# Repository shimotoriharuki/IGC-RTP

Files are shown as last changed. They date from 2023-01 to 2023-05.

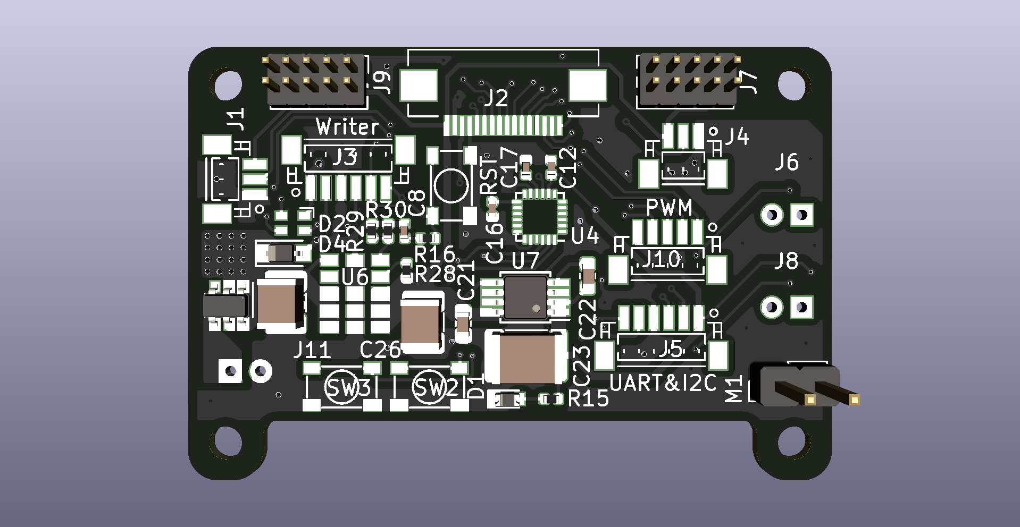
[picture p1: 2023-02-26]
Circuit/main_circuit/robotraceV5-F.png

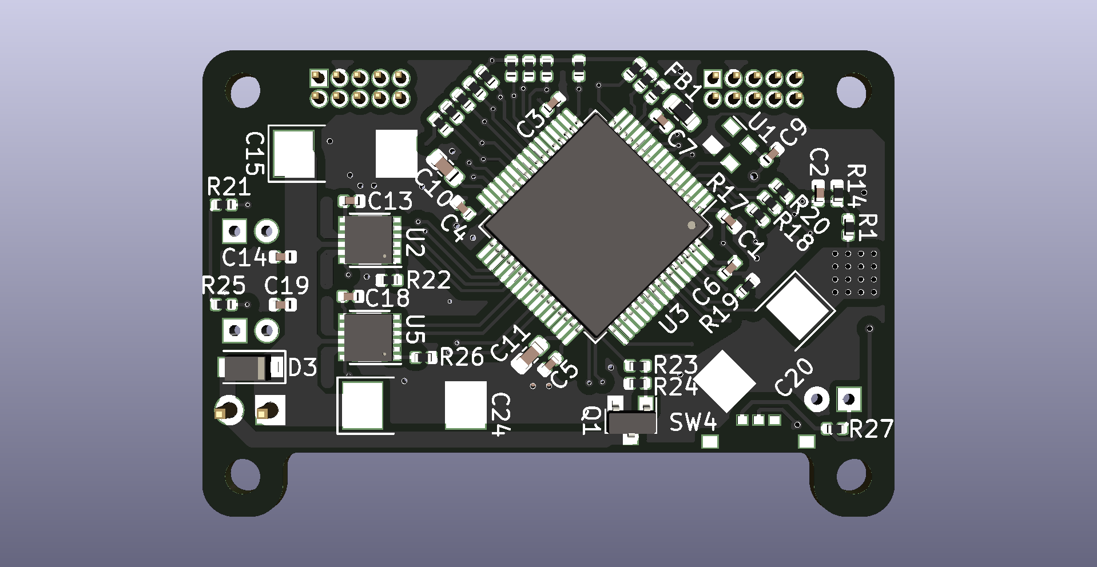
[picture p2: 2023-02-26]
Circuit/main_circuit/robotraceV5-B.png

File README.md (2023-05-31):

# IGC-RTP

IGC-RTPのソフトウェアが含まれるリポジトリです．

# 環境

- CubeIDE 1.5.1
- KiCad 6.0

# 導入方法（たぶん）
1. このリポジトリをフォーク 
2. フォークしたリポジトリをCubeIDEのワークスペースにクローン

（ワークスペースの場所は，Windowsのデフォルトだと `C:\Users\<ユーザー名>\STM32CubeIDE\workspace_<バージョン>`

```
cd <ワークスペースのパス>
git clone https://github.com/shimotoriharuki/IGC-RTP
```

3. CubeIDEを開いて「C/C++ Project」ウィンドウで右クリック
4. 「Import」をクリック
5. 「General」の中にある「Existing Projects int Workspace」をクリック
6. 「Browse」ボタンをクリックしてクローンしてきたディレクトリを選択
# 運用方法
* 基本的にフォークしたリポジトリで開発してください
* コミットは頻繁にして，コミットメッセージは意味のあるものにしてください
* なにか機能を追加したらGitHubからプルリクを送ってください
* `UserSelection.h`で自分の名前のマクロを有効にしてゲインなどのパラメータを切り替えてください．自分の名前以外のマクロはコメントアウトしてください
# 変更の確認手順

```shell
git fetch origin <テストしたいブランチ名>
```

## before

```shell
git remote add upstream <フォーク元のURL> # フォーク元のURLをupstreamという名前で登録 一度やればOK
git fetch upstream # upstreamの変更をローカルに持ってくる
git merge upstream/<ブランチ名> # マスターに変更を持ってくる
```

* https://leico.github.io/TechnicalNote/Git/pull-fork-origin

# Circuitについて

Circuitディレクトリにある制作物は
[IGC8810](https://github.com/IGC8810)の著作物です。許可を得てこのリポジトリで公開しています。

# LICENSE

このソフトウェアパッケージは[3条項BSDのライセンス](https://github.com/shimotoriharuki/IGC-RTP/blob/master/LICENSE)の下、再頒布および使用が使用が許可されます．

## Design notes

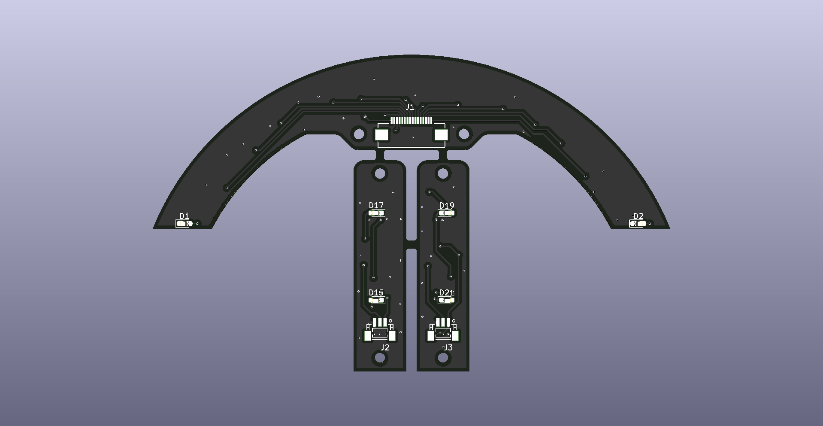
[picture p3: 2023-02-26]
Circuit/sensor_circuit/robotrace_sensorV4_F.png

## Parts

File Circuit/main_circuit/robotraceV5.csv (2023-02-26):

Reference | Quantity | Value | Footprint | Datasheet
C10 C11 | 2 | 2.2ƒÊ | Capacitor_SMD:C_0603_1608Metric | ~
C13 C18 | 2 | 1ƒÊ | Capacitor_SMD:C_0402_1005Metric | ~
C15 C20 | 2 | 68ƒÊ | mcr0:OScapacitor_ECAS | ~
C21 | 1 | 1ƒÊ | Capacitor_SMD:C_0603_1608Metric | ~
C22 | 1 | 0.01ƒÊ | Capacitor_SMD:C_0603_1608Metric | ~
C23 | 1 | 10ƒÊ | Capacitor_SMD:C_1812_4532Metric | ~
C24 | 1 | 100ƒÊ | mcr0:OScapacitor_ECAS | ~
C25 C26 | 2 | 22ƒÊ | Capacitor_SMD:C_1210_3225Metric | ~
C7 C9 C8 C14 C19 C3 C1 C6 C5 C4 C12 C16 C2 C17 | 14 | 0.1ƒÊ | Capacitor_SMD:C_0402_1005Metric | ~
D1 | 1 | green | Diodes_SMD:D_0603 | ~
D2 | 1 | OSTB0603C1C-A | mcr0:OSTB0603C1C-A
D3 | 1 | SS2040FL | Diodes_SMD:D_SOD-123F | ~
D4 | 1 | 14 | Diodes_SMD:D_SOD-323_HandSoldering | ~
FB1 | 1 | Ferrite | Resistor_SMD:R_0603_1608Metric | ~
J10 | 1 | PWM | Connectors_JST:JST_SH_BM05B-SRSS-TB_05x1.00mm_Straight | ~
J11 | 1 | Battery | mcr0:PAconn_01x02 | ~
J2 | 1 | LineADC_IN | mcr0:CN-FFC-SMT2(CN-FFC(0.5)16PD) | ~
J3 | 1 | Debugger | Connectors_JST:JST_SH_BM06B-SRSS-TB_06x1.00mm_Straight | ~
J4 J1 | 2 | maker_IN | Connectors_JST:JST_SH_BM03B-SRSS-TB_03x1.00mm_Straight | ~
J5 | 1 | I2C&UART | Connectors_JST:JST_SH_BM06B-SRSS-TB_06x1.00mm_Straight | ~
J6 J8 | 2 | Motor | mcr0:PAconn_01x02 | ~
J9 J7 | 2 | FTSH-105-01-F-D-K | Pin_Headers:Pin_Header_Straight_2x05_Pitch1.27mm | ~
M1 | 1 | Fan | Pin_Headers:Pin_Header_Straight_1x02_Pitch2.54mm | ~
Q1 | 1 | 2N7002K | Package_TO_SOT_SMD:SOT-23 | https://www.diodes.com/assets/Datasheets/ds30896.pdf
Q2 | 1 | SSM6J808R | mcr0:TSOP-6F_P0.95mm | http://akizukidenshi.com/catalog/g/gI-10454/
R1 | 1 | 2.4k | Resistor_SMD:R_0402_1005Metric | ~
R14 | 1 | 620 | Resistor_SMD:R_0402_1005Metric | ~
R16 | 1 | 100 | Resistor_SMD:R_0402_1005Metric | ~
R17 R29 | 2 | 1.2k | Resistor_SMD:R_0402_1005Metric | ~
R18 | 1 | 680 | Resistor_SMD:R_0402_1005Metric | ~
R19 R21 R25 R15 R28 | 5 | 10k | Resistor_SMD:R_0402_1005Metric | ~
R2 R3 R4 R5 R6 R7 R8 R9 R10 R11 R12 R13 | 12 | R | Resistor_SMD:R_0402_1005Metric | ~
R20 R23 | 2 | 470 | Resistor_SMD:R_0402_1005Metric | ~
R22 R26 | 2 | 14k | Resistor_SMD:R_0402_1005Metric | ~
R27 R24 | 2 | 47k | Resistor_SMD:R_0402_1005Metric | ~
R30 | 1 | 150 | Resistor_SMD:R_0402_1005Metric | ~
SW1 SW3 SW2 | 3 | SW_Push | mylib:SKRPACE010 | ~
SW4 | 1 | SSAJ120100 | mcr0:SSAJ120100 | ~
U1 | 1 | ASDMB-12MHz | Oscillator:Oscillator_SMD_Abracon_ASDMB-4Pin_2.5x2.0mm | https://abracon.com/Oscillators/ASDMB.pdf
U2 U5 | 2 | MAX22201ATC | Package_DFN_QFN:DFN-12-1EP_3x3mm_P0.5mm_EP2.05x2.86mm
U3 | 1 | STM32F405RGTx | Package_QFP:LQFP-64_10x10mm_P0.5mm | http://www.st.com/st-web-ui/static/active/en/resource/technical/document/datasheet/DM00037051.pdf
U4 | 1 | ICM-20648 or MPU-6500 | Sensor_Motion:InvenSense_QFN-24_3x3mm_P0.4mm | http://www.invensense.com/wp-content/uploads/2016/06/DS-000189-ICM-20948-v1.3.pdf
U6 | 1 | LXDC55F | mylib:LXDC55F
U7 | 1 | LT1763-3.3 | Package_SO:MSOP-8_3x3mm_P0.65mm | https://www.analog.com/media/en/technical-documentation/data-sheets/1962fb.pdf

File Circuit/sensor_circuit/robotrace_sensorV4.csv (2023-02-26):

Reference | Quantity | Value | Footprint | Datasheet
C1 C2 C3 C8 C7 C6 C5 C4 C10 C9 C11 C13 C12 C14 | 14 | 0.1ƒÊ | Capacitor_SMD:C_0603_1608Metric | ~
D1 D2 D15 D17 D21 D19 | 6 | LED | LED_SMD:LED_0603_1608Metric_Castellated | ~
D9 D3 D8 D14 D7 D13 D6 D12 D5 D11 D4 D10 D16 D18 D20 D22 | 16 | IRLED | LED_SMD:LED_0603_1608Metric_Castellated | ~
J1 | 1 | line_sens | mcr0:CN-FFC-SMT2(CN-FFC(0.5)16PD) | ~
J2 | 1 | maker_outL | Connectors_JST:JST_SH_BM03B-SRSS-TB_03x1.00mm_Straight | ~
J3 | 1 | maker_outR | Connectors_JST:JST_SH_BM03B-SRSS-TB_03x1.00mm_Straight | ~
Q1 Q2 Q3 Q4 Q5 Q6 Q7 Q8 Q9 Q10 Q11 Q12 | 12 | PT | LED_SMD:LED_0603_1608Metric_Castellated | ~
R1 R2 R15 R18 R24 R21 | 6 | 1k | Resistor_SMD:R_0603_1608Metric | ~
R16 R19 R22 R25 | 4 | 100 | Resistor_SMD:R_0603_1608Metric | ~
R3 R8 R7 R6 R5 R4 R17 R20 R23 R26 | 10 | 10k | Resistor_SMD:R_0603_1608Metric | ~
R9 R14 R13 R12 R11 R10 | 6 | 4 | Resistor_SMD:R_0603_1608Metric | ~
U1 U6 U5 U4 U3 U2 | 6 | NJU6080 | TO_SOT_Packages_SMD:SOT-23-6
U7 U9 U10 U12 | 4 | S7136 | mcr0:S7136 | https://akizukidenshi.com/catalog/g/gI-02425/
U8 U11 | 2 | TC7S32F | Package_SO:TSOP-5_1.65x3.05mm_P0.95mm | http://www.ti.com/lit/sg/scyt129e/scyt129e.pdf

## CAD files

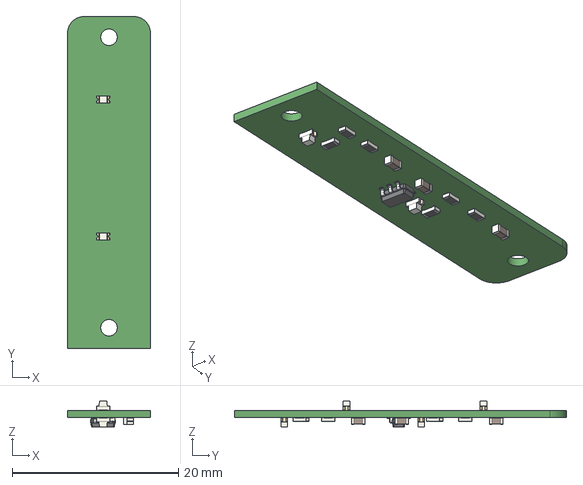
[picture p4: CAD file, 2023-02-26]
Circuit/sensor_circuit/robotrace_sensorV4_left_sens_only.step
10.0 x 40.0 x 3.10 mm

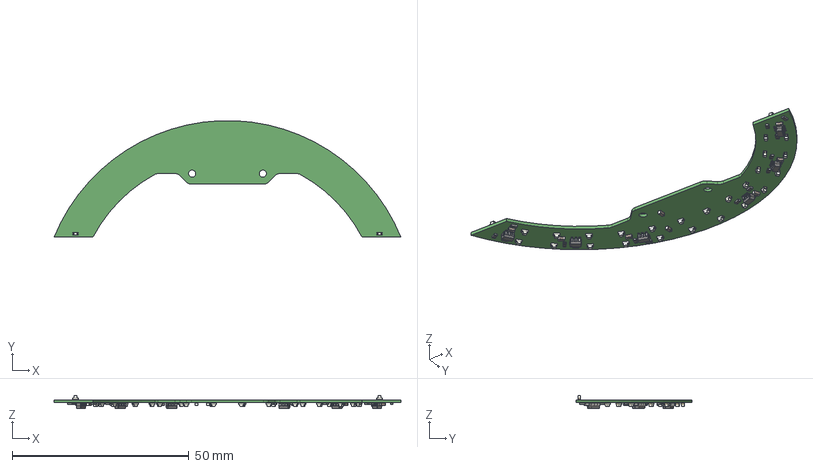
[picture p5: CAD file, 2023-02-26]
Circuit/sensor_circuit/robotrace_sensorV4_line_sens_only.step
98.2 x 32.9 x 3.55 mm

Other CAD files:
Circuit/sensor_circuit/robotrace_sensorV4_right_sens_only.step

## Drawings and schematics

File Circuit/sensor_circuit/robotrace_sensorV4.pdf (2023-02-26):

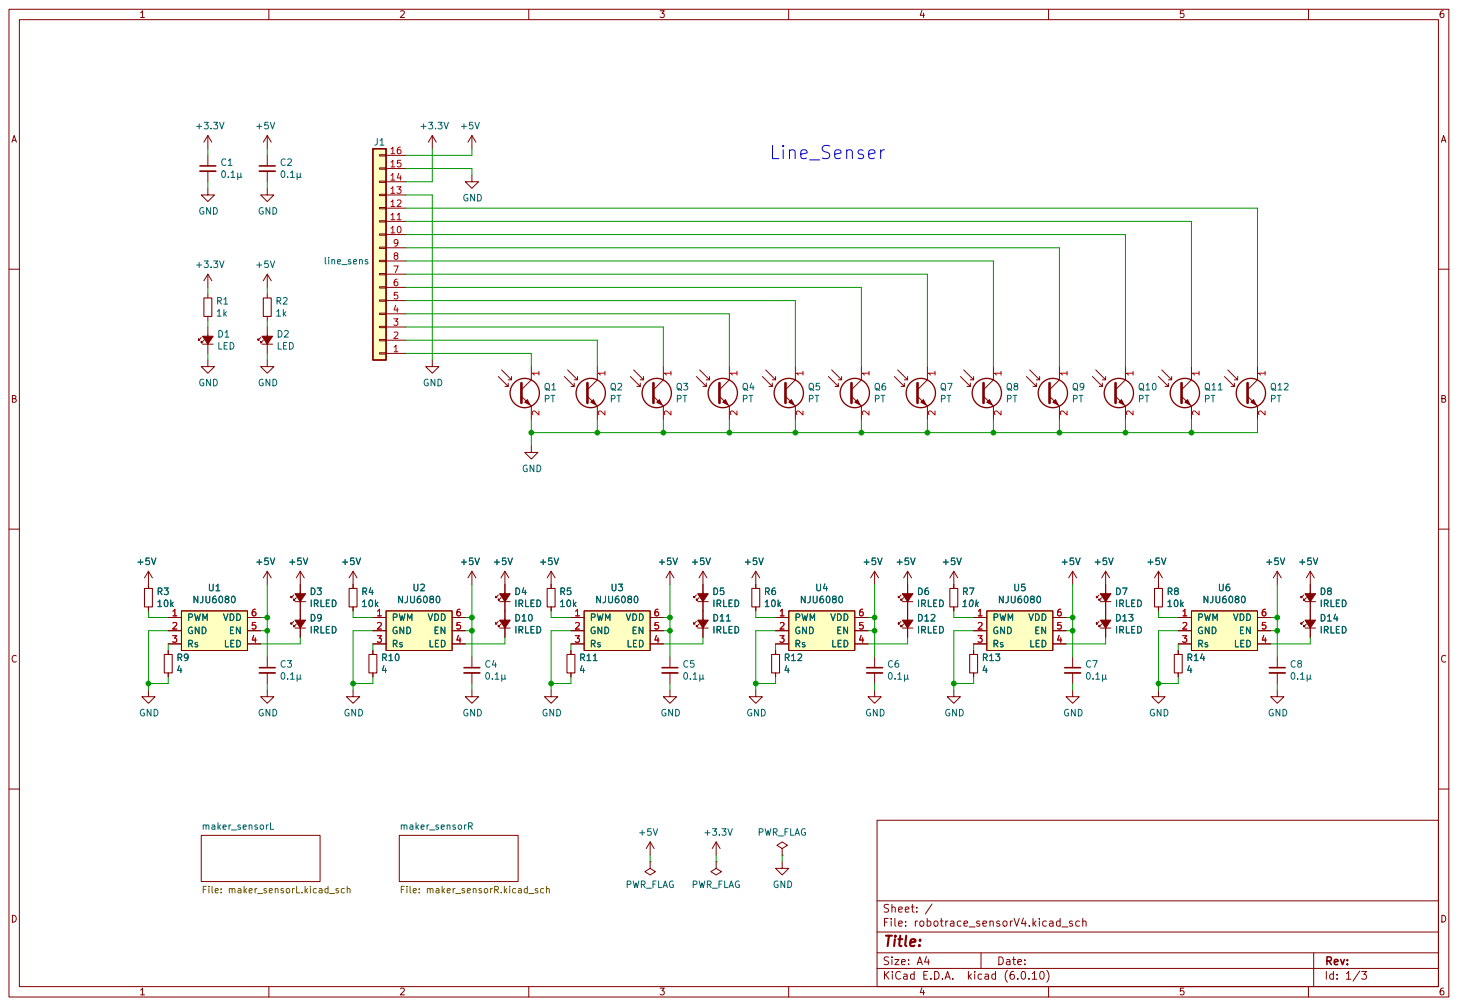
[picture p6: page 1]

11
10

1 2 Q5 PT PWM 1 GND 2 Rs 3

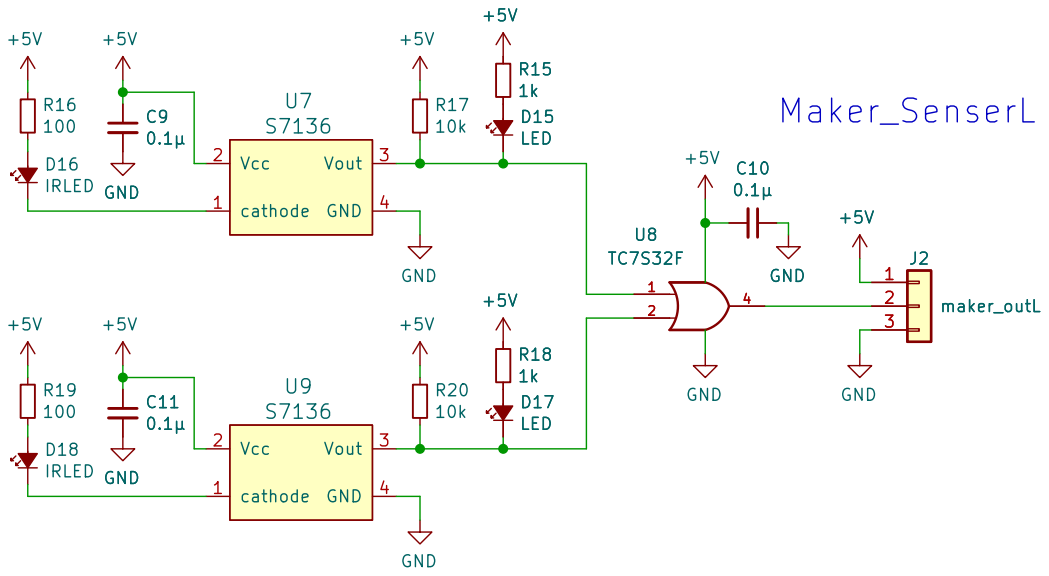
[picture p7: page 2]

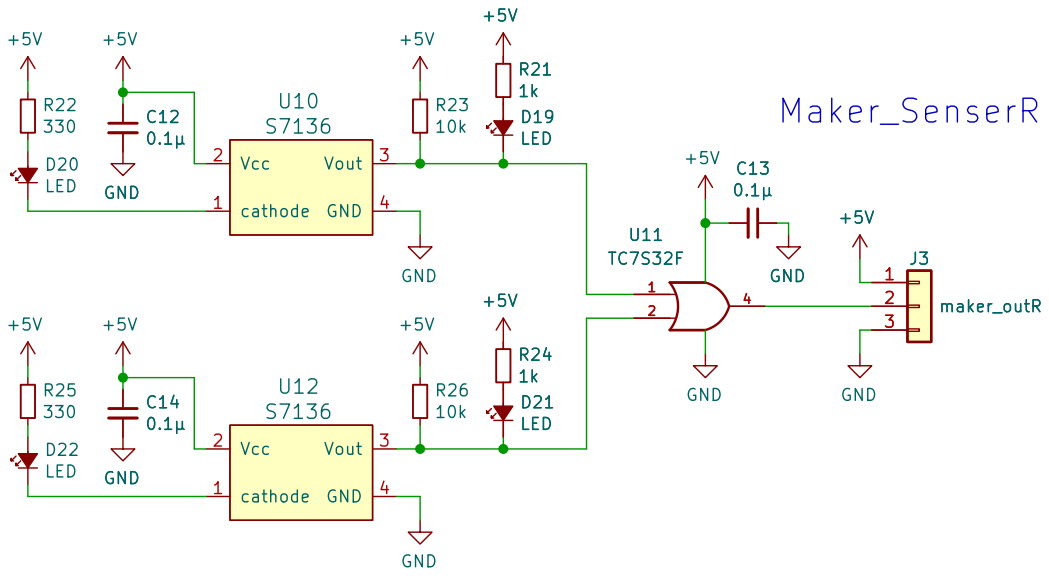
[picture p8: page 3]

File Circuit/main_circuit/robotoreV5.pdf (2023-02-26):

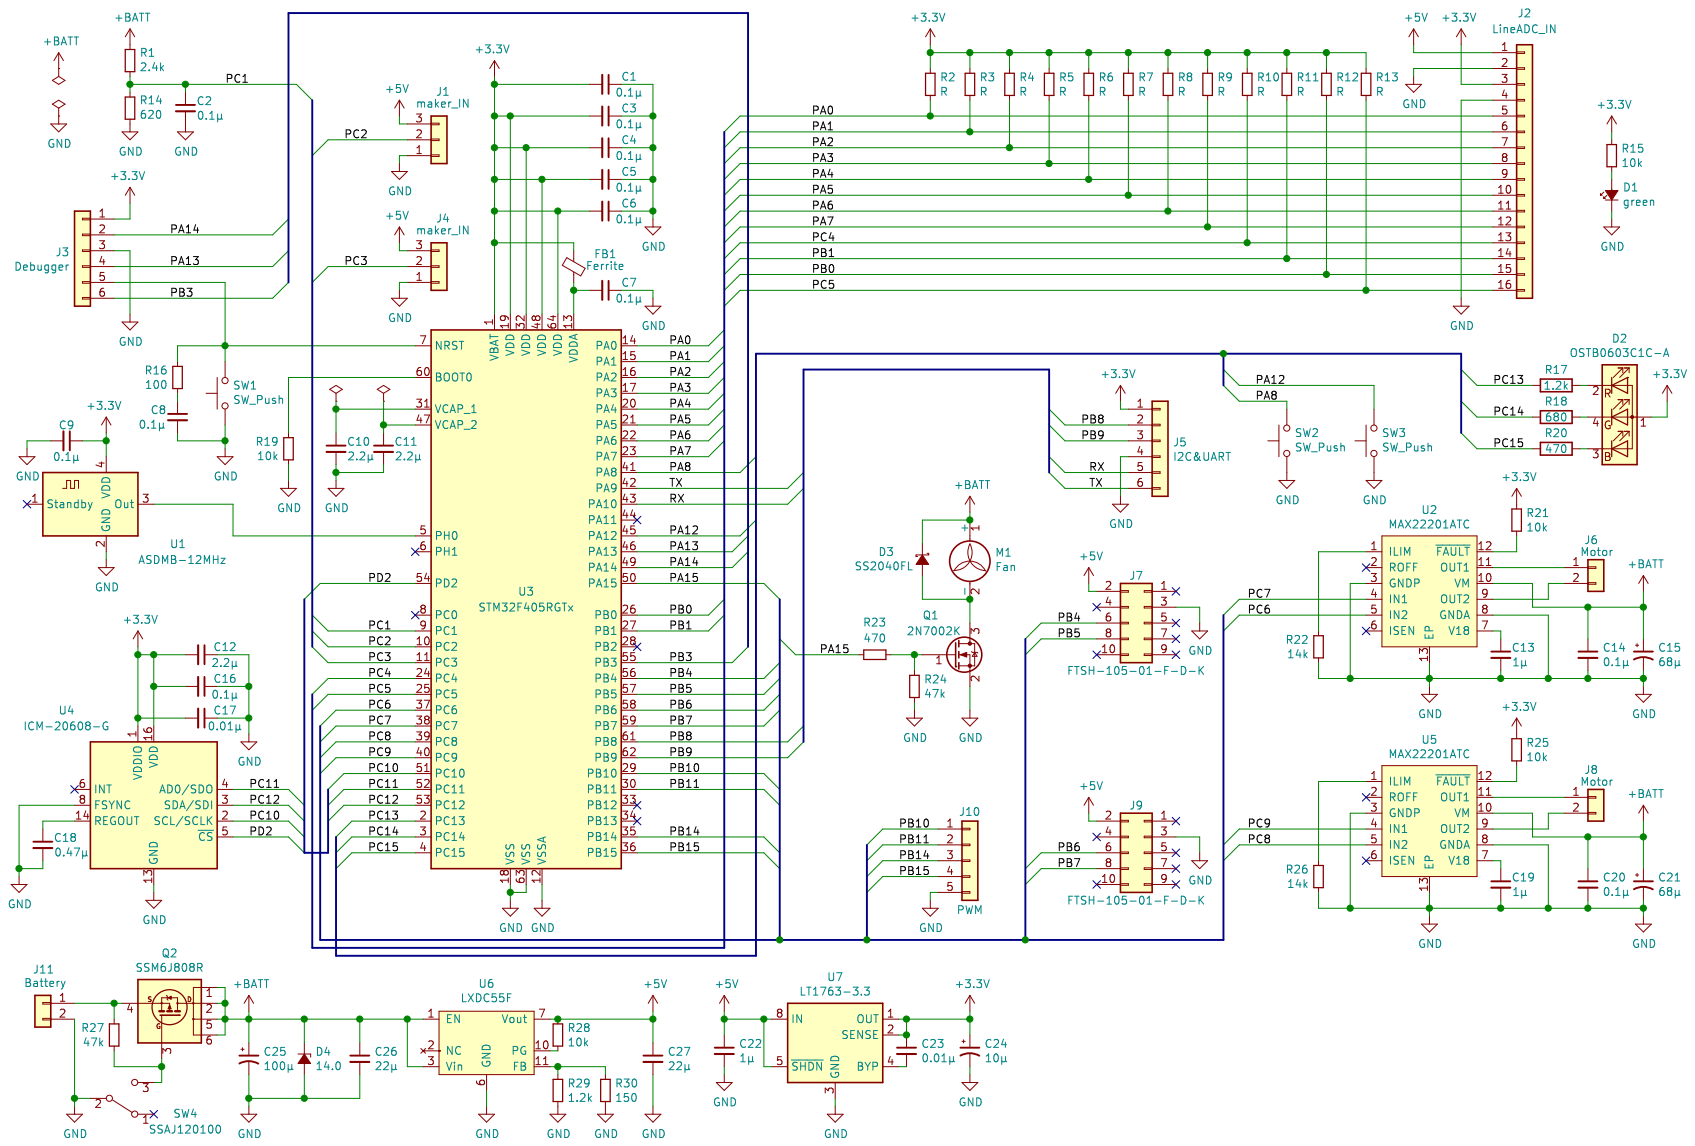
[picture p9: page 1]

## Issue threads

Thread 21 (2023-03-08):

マイコンがリセット状態だとファンが回る

shimotoriharuki, 2023-03-08:
書き込み中やリセットボタン押している間だとPA15がHIGHになるらしく，ファンがずっと回り続ける．
モータに1s以上の電圧をかけたくないのでソフトウェアでリミットをかけているが，リセット時に回られるとリミットが効かないのでなんとかしたい．

shimotoriharuki, 2023-03-08:
リセット時のマイコンのピンの状態を指定できるとよさげ．

shimotoriharuki, 2023-03-10:
マイコンリセット時にFETのゲート電圧がどうなっているか確認してけろ

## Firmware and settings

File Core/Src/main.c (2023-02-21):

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
/* Includes ------------------------------------------------------------------*/
#include "main.h"

/* USER CODE BEGIN Includes */
#include "Motor.h"
#include "LineSensor.h"
#include "SideSensor.h"
#include "LineChase.h"
#include "Running.h"
#include "MPU6500.h"
#include "IMU.h"
#include "LED.h"
#include "Switch.h"
#include "BatteryChecker.h"
#include "stdio.h"
#include "Logger.h"

/* USER CODE END Includes */

ADC_HandleTypeDef hadc1;
ADC_HandleTypeDef hadc2;
DMA_HandleTypeDef hdma_adc1;
DMA_HandleTypeDef hdma_adc2;

I2C_HandleTypeDef hi2c1;

SPI_HandleTypeDef hspi3;

TIM_HandleTypeDef htim2;
TIM_HandleTypeDef htim3;
TIM_HandleTypeDef htim4;
TIM_HandleTypeDef htim6;
TIM_HandleTypeDef htim7;
TIM_HandleTypeDef htim8;
TIM_HandleTypeDef htim12;

UART_HandleTypeDef huart1;

/* USER CODE BEGIN PV */

uint32_t timer, timer1;
uint16_t second_run_flag;

uint16_t mode_selector = 0;



/* USER CODE END PV */

void SystemClock_Config(void);
static void MX_GPIO_Init(void);
static void MX_DMA_Init(void);
static void MX_ADC1_Init(void);
static void MX_I2C1_Init(void);
static void MX_TIM2_Init(void);
static void MX_TIM3_Init(void);
static void MX_TIM4_Init(void);
static void MX_TIM8_Init(void);
static void MX_SPI3_Init(void);
static void MX_TIM12_Init(void);
static void MX_USART1_UART_Init(void);
static void MX_TIM6_Init(void);
static void MX_TIM7_Init(void);
static void MX_ADC2_Init(void);
/* USER CODE BEGIN 0 */
#ifdef __GNUC__
	#define PUTCHAR_PROTOTYPE int __io_putchar(int ch)
#else
	#define PUTCHAR_PROTOTYPE int fputc(int ch, FILE *f)
#endif /*__GNUC__*/

PUTCHAR_PROTOTYPE{
	HAL_UART_Transmit(&huart1, (uint8_t*)&ch, 1, 0xFFFF);
	return ch;
}

void HAL_TIM_PeriodElapsedCallback(TIM_HandleTypeDef *htim)
{
   if(htim->Instance == TIM6){ //1ms
		timer++;
		updateEncoderCnt(); //Do not move from HERE!!

		batteryCheckFlip();
		updateIMUValue();
		updateAnalogSensor();
		updateSideSensorStatus();

		calculateVelocityControlFlip();
		calculateLineFollowingTermFlip();
		lineTraceFlip();
		checkCourseOut();

		runningFlip();
		motorCtrlFlip();
		droneMotorCtrlFlip();

		resetEncoderCnt(); //Do not move from HERE!!
   }
   if(htim->Instance == TIM7){ //0.1ms
       timer1++;
       storeAnalogSensorBuffer();
   }
}

void HAL_GPIO_EXTI_Callback(uint16_t GPIO_Pin)
{
	if(GPIO_Pin == GPIO_PIN_2){ //leght
		updateStatusLeftExti();
	}

	else if(GPIO_Pin == GPIO_PIN_3){ //right
		updateStatusRightExti();
	}
}

void init(void)
{
	initEncoder();
	initADC();
	initBatteryChecker();
	initLog();
	setLED('N');
	initGyro();
	if(initGyro() == 1){
		setRGB('B');
		HAL_Delay(1000);
		setRGB('b');
	}
	else{
		setRGB('R');
		HAL_Delay(1000);
		setRGB('r');

	}
	second_run_flag = 1;

	HAL_TIM_Base_Start_IT(&htim6); //Timer interrupt
	HAL_TIM_Base_Start_IT(&htim7); //Timer interrupt
	initMotor();

	setLED('R');
    sensorCalibration();

	HAL_Delay(500);
	if(isBatteryLow() == true){
		uint16_t i = 0;
		for(i = 0; i < 10; i++){
			setLED('R');
			HAL_Delay(33);
			setLED('G');
			HAL_Delay(33);
			setLED('B');
			HAL_Delay(33);
		}
	}
}

/* USER CODE END 0 */

/**
  * @brief  The application entry point.
  * @retval int
  */
int main(void)
{
  /* MCU Configuration--------------------------------------------------------*/

  /* Reset of all peripherals, Initializes the Flash interface and the Systick. */
  HAL_Init();

  /* Configure the system clock */
  SystemClock_Config();

  /* Initialize all configured peripherals */
  MX_GPIO_Init();
  MX_DMA_Init();
  MX_ADC1_Init();
  MX_I2C1_Init();
  MX_TIM2_Init();
  MX_TIM3_Init();
  MX_TIM4_Init();
  MX_TIM8_Init();
  MX_SPI3_Init();
  MX_TIM12_Init();
  MX_USART1_UART_Init();
  MX_TIM6_Init();
  MX_TIM7_Init();
  MX_ADC2_Init();
  /* USER CODE BEGIN 2 */

  init();

  /*
 	//startLineTrace();
	startVelocityControl();
	setTargetVelocity(1.0);
	//setMotor(300, 300);
	HAL_Delay(500);
	//setMotor(-2000, -2000);
	setTargetVelocity(0.0);
	//stopVelocityControl();
	//setMotor(0, 0);
	*/

  //setMotor(300, 300);
  //while(1);


  /* USER CODE END 2 */

  /* Infinite loop */
  /* USER CODE BEGIN WHILE */
  while (1)
  {

	  if(getSwitchStatus('L') == true){
		  mode_selector++;
		  HAL_Delay(500);
		  if(mode_selector >= 6) mode_selector = 0;
	  }

	  switch(mode_selector){
		  case 0:
			  setLED('B');

			  if(getSwitchStatus('R') == true){ //run
				  setLED('N');
				  setRunMode(1);
				  setVelocityRange(1.7, 1.7);
				  HAL_Delay(500);

				  running();
			  }

			  break;

		  case 1:
			  setLED('C');

			  if(getSwitchStatus('R') == true) { //run
				  setLED('N');
				  setRunMode(2);
				  setVelocityRange(1.7, 3.0);
				  setAccDec(5, 2);
				  setStraightRadius(1000); //Do Not Change
				  HAL_Delay(500);

				  running();
			  }

			  break;

		  case 2:
			  setLED('Y');

			  if(getSwitchStatus('R') == true) { //run

				  setLED('N');
				  setRunMode(3);
				  setVelocityRange(1.7, 4.0);
				  setAccDec(8, 3);
				  setStraightRadius(1000); //Do Not Change
				  HAL_Delay(500);

				  running();
			  }

			  break;

		  case 3:
			  setLED('M');
			  if(getSwitchStatus('R') == true) {

				  setLED('N');
				  setRunMode(3);
				  setVelocityRange(1.6, 5.0);
				  setAccDec(8, 2); //6, 2
				  setStraightRadius(1000); //Do Not Change
				  HAL_Delay(500);

				  running();
			  }

			  break;

		  case 4:
			  setLED('R');
			  if(getSwitchStatus('R') == true) {

				  setLED('N');
				  setRunMode(3);
				  setVelocityRange(1.8, 6.5); //1.7, 6.0
				  setAccDec(8, 3); //8, 3
				  setStraightRadius(1000); //Do Not Change
				  HAL_Delay(500);

				  running();
			  }
			  break;

		  case 5:
			  setLED('G');
			  if(getSwitchStatus('R') == true) {
				  setLED('N');
				  loadDistance();
				  loadTheta();
				  loadCross();
				  loadSide();
				  loadDebug();

				  setRunMode(2);
				  setVelocityRange(1.8, 5.0);
				  setAccDec(8, 3);
				  createVelocityTable();

				  printf("Distance, Theta\r\n");
				  for(uint16_t i = 0; i < getDistanceLogSize(); i++){
					 printf("%f, %f\r\n", getDistanceLog(i), getThetaLog(i));
				  }

				  printf("9999, 9999\r\n");

				  printf("TargetVelocity, CurrentVelocity\r\n");
				  uint16_t size = getDebugLogSize();
				  for(uint16_t i = 0; i < size; i = i+2){
					 printf("%f, %f\r\n", getDebugLog(i), getDebugLog(i + 1));
				  }
			  }

			  break;
	  };

	  /*
	  //LED
	  HAL_GPIO_WritePin(GPIOC, GPIO_PIN_13, GPIO_PIN_SET);
	  HAL_GPIO_WritePin(GPIOC, GPIO_PIN_14, GPIO_PIN_SET);
	  HAL_GPIO_WritePin(GPIOC, GPIO_PIN_15, GPIO_PIN_SET);

	  //motor_L = 900;
	  //motor_R = 500;
	  HAL_Delay(1000);

	  //LED
	  HAL_GPIO_WritePin(GPIOC, GPIO_PIN_13, GPIO_PIN_RESET);
	  HAL_GPIO_WritePin(GPIOC, GPIO_PIN_14, GPIO_PIN_RESET);
	  HAL_GPIO_WritePin(GPIOC, GPIO_PIN_15, GPIO_PIN_RESET);

	  HAL_Delay(1000);
	  */
    /* USER CODE END WHILE */

    /* USER CODE BEGIN 3 */
  }
  /* USER CODE END 3 */
}

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


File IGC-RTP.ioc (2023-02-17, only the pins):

Mcu.UserName=STM32F405RGTx
PA0-WKUP.Signal=ADCx_IN0
PA1.Signal=ADCx_IN1
PA10.Signal=USART1_RX
PA12.GPIO_Label=SWITCH1
PA12.Signal=GPIO_Input
PA13.Signal=SYS_JTMS-SWDIO
PA14.Signal=SYS_JTCK-SWCLK
PA15.GPIO_Label=FAN_MOTOR_PWM
PA15.Signal=S_TIM2_CH1_ETR
PA2.Signal=ADCx_IN2
PA3.Signal=ADCx_IN3
PA4.Signal=ADCx_IN4
PA5.Signal=ADCx_IN5
PA6.Signal=ADCx_IN6
PA7.Signal=ADCx_IN7
PA8.GPIO_Label=SWITCH2
PA8.Signal=GPIO_Input
PA9.Signal=USART1_TX
PB0.Signal=ADCx_IN8
PB1.Signal=ADCx_IN9
PB10.GPIO_Label=DRONE_MOTOR_PWM1
PB10.Signal=S_TIM2_CH3
PB11.GPIO_Label=DRONE_MOTOR_PWM2
PB11.Signal=S_TIM2_CH4
PB14.GPIO_Label=DRONE_MOTOR_PWM4
PB14.Signal=S_TIM12_CH1
PB15.GPIO_Label=DRONE_MOTOR_PWM3
PB15.Signal=S_TIM12_CH2
PB3.Signal=SYS_JTDO-SWO
PB4.GPIO_Label=ENCODER1_A
PB4.Signal=S_TIM3_CH1
PB5.GPIO_Label=ENCODER1_B
PB5.Signal=S_TIM3_CH2
PB6.GPIO_Label=ENCODER2_A
PB6.Signal=S_TIM4_CH1
PB7.GPIO_Label=ENCODER2_B
PB7.Signal=S_TIM4_CH2
PB8.Signal=I2C1_SCL
PB9.Signal=I2C1_SDA
PC1.GPIO_Label=BATTERY_ADC
PC1.Signal=ADCx_IN11
PC10.Signal=SPI3_SCK
PC11.Signal=SPI3_MISO
PC12.Signal=SPI3_MOSI
PC13-ANTI_TAMP.GPIO_Label=LED_R
PC13-ANTI_TAMP.Signal=GPIO_Output
PC14-OSC32_IN.GPIO_Label=LED_G
PC14-OSC32_IN.Signal=GPIO_Output
PC15-OSC32_OUT.GPIO_Label=LED_B
PC15-OSC32_OUT.Signal=GPIO_Output
PC2.Signal=GPXTI2
PC3.Signal=GPXTI3
PC4.Signal=ADCx_IN14
PC5.Signal=ADCx_IN15
PC6.GPIO_Label=DRIVE_MOTOR1_PWM2
PC6.Signal=S_TIM8_CH1
PC7.GPIO_Label=DRIVE_MOTOR1_PWM1
PC7.Signal=S_TIM8_CH2
PC8.GPIO_Label=DRIVE_MOTOR2_PWM2
PC8.Signal=S_TIM8_CH3
PC9.GPIO_Label=DRIVE_MOTOR2_PWM1
PC9.Signal=S_TIM8_CH4
PD2.GPIO_Label=SPI_CS
PD2.Signal=GPIO_Output
PH0-OSC_IN.Signal=RCC_OSC_IN
PH1-OSC_OUT.Signal=RCC_OSC_OUT

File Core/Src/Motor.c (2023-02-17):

/*
 * Motor.c
 *
 *  Created on: Jan 26, 2023
 *      Author: Haruki SHIMOTORI
 */

#include <Motor.h>

TIM_HandleTypeDef htim8, htim2;

static int16_t motor_l, motor_r;
static int16_t drone_motor_l, drone_motor_r;
int16_t mon_rev_l, mon_rev_r;

void initMotor(void)
{
	HAL_TIM_PWM_Start(&htim8, TIM_CHANNEL_1); //PWM start
	HAL_TIM_PWM_Start(&htim8, TIM_CHANNEL_2); //PWM start
	HAL_TIM_PWM_Start(&htim8, TIM_CHANNEL_3); //PWM start
	HAL_TIM_PWM_Start(&htim8, TIM_CHANNEL_4); //PWM start

	HAL_TIM_PWM_Start(&htim2, TIM_CHANNEL_3); //PWM start
	HAL_TIM_PWM_Start(&htim2, TIM_CHANNEL_4); //PWM start

	//motor driver wakeup
	__HAL_TIM_SET_COMPARE(&htim8, TIM_CHANNEL_1, MAX_COUNTER_PERIOD);
	__HAL_TIM_SET_COMPARE(&htim8, TIM_CHANNEL_2, MAX_COUNTER_PERIOD);
	__HAL_TIM_SET_COMPARE(&htim8, TIM_CHANNEL_3, MAX_COUNTER_PERIOD);
	__HAL_TIM_SET_COMPARE(&htim8, TIM_CHANNEL_4, MAX_COUNTER_PERIOD);
	HAL_Delay(100);
}

void motorCtrlFlip(void)
{
	int16_t motor_pwm_l, motor_pwm_r;
	int16_t reverse_motor_l, reverse_motor_r;

	if(motor_l >= 0){
		reverse_motor_l = MAX_COUNTER_PERIOD - motor_l;
		motor_pwm_l = reverse_motor_l;
		// motor1
		__HAL_TIM_SET_COMPARE(&htim8, TIM_CHANNEL_3, motor_pwm_l);
		__HAL_TIM_SET_COMPARE(&htim8, TIM_CHANNEL_4, MAX_COUNTER_PERIOD);
	}
	else{
		reverse_motor_l = MIN_COUNTER_PERIOD - motor_l;
		motor_pwm_l = reverse_motor_l * (-1) ;
		// motor1
		__HAL_TIM_SET_COMPARE(&htim8, TIM_CHANNEL_3, MAX_COUNTER_PERIOD);
		__HAL_TIM_SET_COMPARE(&htim8, TIM_CHANNEL_4, motor_pwm_l);
	}

	if(motor_r >= 0){
		reverse_motor_r = MAX_COUNTER_PERIOD - motor_r;
		motor_pwm_r = reverse_motor_r;
		// motor1
		__HAL_TIM_SET_COMPARE(&htim8, TIM_CHANNEL_1, MAX_COUNTER_PERIOD);
		__HAL_TIM_SET_COMPARE(&htim8, TIM_CHANNEL_2, motor_pwm_r);
	}
	else{
		reverse_motor_r = MIN_COUNTER_PERIOD - motor_r;
		motor_pwm_r = reverse_motor_r * (-1);
		//motor2
		__HAL_TIM_SET_COMPARE(&htim8, TIM_CHANNEL_1, motor_pwm_r);
		__HAL_TIM_SET_COMPARE(&htim8, TIM_CHANNEL_2, MAX_COUNTER_PERIOD);
	}
	mon_rev_l = reverse_motor_l;
	mon_rev_r = reverse_motor_r;

}

void droneMotorCtrlFlip(void)
{
	__HAL_TIM_SET_COMPARE(&htim2, TIM_CHANNEL_3, drone_motor_l);
	__HAL_TIM_SET_COMPARE(&htim2, TIM_CHANNEL_4, drone_motor_r);

	mon_rev_l = drone_motor_l;
	mon_rev_r = drone_motor_r;

}

void setMotor(int16_t l, int16_t r)
{
	if(l >= MAX_COUNTER_PERIOD) l = MAX_COUNTER_PERIOD;
	else if(l <= MIN_COUNTER_PERIOD) l = MIN_COUNTER_PERIOD;

	if(r >= MAX_COUNTER_PERIOD) r = MAX_COUNTER_PERIOD;
	else if(r <= MIN_COUNTER_PERIOD) r = MIN_COUNTER_PERIOD;

	motor_l = l;
	motor_r = r;
}


void setDroneMotor(int16_t l, int16_t r)
{
	l = abs(l);
	r = abs(r);

	if(l >= DRONE_MAX_COUNTER_PERIOD) l = DRONE_MAX_COUNTER_PERIOD;
	if(r >= DRONE_MAX_COUNTER_PERIOD) r = DRONE_MAX_COUNTER_PERIOD;

	drone_motor_l = l;
	drone_motor_r = r;
}

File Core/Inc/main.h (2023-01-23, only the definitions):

#define LED_R_Pin GPIO_PIN_13
#define LED_R_GPIO_Port GPIOC
#define LED_G_Pin GPIO_PIN_14
#define LED_G_GPIO_Port GPIOC
#define LED_B_Pin GPIO_PIN_15
#define LED_B_GPIO_Port GPIOC
#define BATTERY_ADC_Pin GPIO_PIN_1
#define BATTERY_ADC_GPIO_Port GPIOC
#define DRONE_MOTOR_PWM1_Pin GPIO_PIN_10
#define DRONE_MOTOR_PWM1_GPIO_Port GPIOB
#define DRONE_MOTOR_PWM2_Pin GPIO_PIN_11
#define DRONE_MOTOR_PWM2_GPIO_Port GPIOB
#define DRONE_MOTOR_PWM4_Pin GPIO_PIN_14
#define DRONE_MOTOR_PWM4_GPIO_Port GPIOB
#define DRONE_MOTOR_PWM3_Pin GPIO_PIN_15
#define DRONE_MOTOR_PWM3_GPIO_Port GPIOB
#define DRIVE_MOTOR1_PWM2_Pin GPIO_PIN_6
#define DRIVE_MOTOR1_PWM2_GPIO_Port GPIOC
#define DRIVE_MOTOR1_PWM1_Pin GPIO_PIN_7
#define DRIVE_MOTOR1_PWM1_GPIO_Port GPIOC
#define DRIVE_MOTOR2_PWM2_Pin GPIO_PIN_8
#define DRIVE_MOTOR2_PWM2_GPIO_Port GPIOC
#define DRIVE_MOTOR2_PWM1_Pin GPIO_PIN_9
#define DRIVE_MOTOR2_PWM1_GPIO_Port GPIOC
#define SWITCH2_Pin GPIO_PIN_8
#define SWITCH2_GPIO_Port GPIOA
#define SWITCH1_Pin GPIO_PIN_12
#define SWITCH1_GPIO_Port GPIOA
#define FAN_MOTOR_PWM_Pin GPIO_PIN_15
#define FAN_MOTOR_PWM_GPIO_Port GPIOA
#define SPI_CS_Pin GPIO_PIN_2
#define SPI_CS_GPIO_Port GPIOD
#define ENCODER1_A_Pin GPIO_PIN_4
#define ENCODER1_A_GPIO_Port GPIOB
#define ENCODER1_B_Pin GPIO_PIN_5
#define ENCODER1_B_GPIO_Port GPIOB
#define ENCODER2_A_Pin GPIO_PIN_6
#define ENCODER2_A_GPIO_Port GPIOB
#define ENCODER2_B_Pin GPIO_PIN_7
#define ENCODER2_B_GPIO_Port GPIOB

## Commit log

2023-01-15 init トレースの関数はできてそう
2023-01-15 走れそうなプログラムはつくった
2023-01-15 はしった！！
2023-01-17 MPU6500 who am iできた
2023-01-17 Z軸の値読めた
2023-01-17 書き直してZ軸読めた
2023-01-17 書き直してジャイロの値すべて読めた
2023-01-18 エンコーダの値読めた
2023-01-23 ignore編集
2023-01-23 soiyaをついか
2023-01-23 ソイヤ２ついか！！
2023-01-23 getEncoderのワーニングを解消
2023-01-23 init関数に初期化をまとめた
2023-01-23 soiyaを削除
2023-01-23 README更新
2023-01-23 コメント追加
2023-01-26 りゅうくとくらべて左のモーターがなぜか逆に回るので正負を逆転しちゃった
2023-01-26 はしった
2023-01-26 クロック周波数変更
2023-01-26 モータ.h作り中
2023-01-27 Motor.hできた
2023-01-27 LineSensor.h追加
2023-01-27 SideSensor.h追加
2023-01-27 Encoder.hを改良
2023-01-27 周波数変更
2023-01-28 名前変更したり
2023-01-28 名前変更とか
2023-01-28 名前変更
2023-01-28 場所変更
2023-01-28 速度制御追加とユーザー選択機能（仮）追加
2023-01-28 マックスで逆回転すると変になるバグ修正
2023-01-28 多分止まるようになった
2023-01-28 たぶん完走するやつ
2023-02-09 i7のやつを持ってきた
2023-02-09 フラッシュ読み書きできた
2023-02-11 テーブル作成までできた
2023-02-11 二次走行っぽいのできた
2023-02-12 logInitに変更
2023-02-12 ゲインを分けtあ
2023-02-12 マージ前
2023-02-12 LEDとSwitch追加
2023-02-12 レファクタリング
2023-02-12 電圧監視を追加
2023-02-12 バッテリー低いときわかるようにした
2023-02-12 pull前
2023-02-12 ログが取れていることは確認
2023-02-12 速度テーブルはつくれているけど速度が更新されているか未確認
2023-02-13 二次走行できそう
2023-02-13 緊急停止準備OKただし止まらない
2023-02-13 サイドセンサの処理を変更
2023-02-13 緊急停止できた
2023-02-13 緊急停止処理の確認できた
2023-02-14 クロスライン補正ははいったはず
2023-02-14 センサーのキャリブレーションできたっぽい
2023-02-14 キャリブレーションのチェックもできた
2023-02-14 ゲインの変更
2023-02-14 サイドの補正が動いていそう
2023-02-14 ギア比などユーザーごとに変更させたい途中
2023-02-15 同じ曲率が続いたタイミングで補正が入るようにできた（たぶん）
2023-02-15 ペラ動くようにした
2023-02-15 クロスラインで止まる
2023-02-15 サイドセンサの無視する距離を伸ばしたらよさそう
2023-02-15 速度制御よりライン追従を優先にした（ちゃんと確認してない）
2023-02-15 速度変わるときにIのリセットを実装
2023-02-15 クロスラインで強制的に最高速度にするやつと速度テーブルをシフトするやつ実装
2023-02-15 減速の距離マージンを実装できたと思われる
2023-02-16 速度計画を比率で計画するやつ実装
2023-02-16 SPIの通信速度を落とした
2023-02-16 1.8, 5.0で完走
2023-02-16 IMUとの通信をZgだけにしてみた
2023-02-16 速度の追従が追いついていない．一旦I項のリセットを切った
2023-02-16 速度ゲインの見直し中
2023-02-16 速度ゲイン調整した
2023-02-16 速度計画修正
2023-02-16 加速悪い
2023-02-17 とりあえずプッシュ用
2023-02-17 1.4, 4.0が走った
2023-02-17 1.7, 6.0はしった
2023-02-17 IMUのローパスフィルタ弱くした
2023-02-17 クロスライン読んだらサイドの補正フラグたてた
2023-02-17 ５走行分のパラメータ用意
2023-02-17 連続の曲率判定のしきい値を変更
2023-02-17 走るか走らないかくらい
2023-02-17 二次関数の速度計画ならはしる
2023-02-17 クロスライン補正が切れてたので復活
2023-02-18 とりあえずマゼンタ走った
2023-02-18 ライントレースのゲイン調整と連続曲率の判定をゆるくした
2023-02-18 クロス無視の距離を短くしたのとゴール以降の目標値を3.0に変更
2023-02-18 いちおう全パラメータ走った
2023-02-18 加速のマージンを追加
2023-02-18 加速のマージン動いてそう全パラメータ動いた
2023-02-18 5走行目攻め攻めパラメータ完走
2023-02-18 ゲイン落とした
2023-02-18 ゲイン下げても速度は追いつかないのでもどした．減速はこれ以上攻めると無理そうなので戻した
2023-02-21 全国3位のプログラム
2023-02-26 回路情報を追加
2023-02-26 回路情報追加
    [maker_sensorL.kicad_sch, maker_sensorL.sch, maker_sensorR.kicad_sch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]

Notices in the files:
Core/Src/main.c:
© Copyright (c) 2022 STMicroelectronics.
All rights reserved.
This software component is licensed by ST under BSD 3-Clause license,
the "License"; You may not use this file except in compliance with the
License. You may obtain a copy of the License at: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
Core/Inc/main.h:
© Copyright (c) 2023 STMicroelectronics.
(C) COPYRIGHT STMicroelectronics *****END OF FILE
